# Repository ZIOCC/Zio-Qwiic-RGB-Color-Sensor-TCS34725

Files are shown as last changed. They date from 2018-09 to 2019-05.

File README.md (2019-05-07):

# Zio Qwiic RGB Color Sensor (TCS34725)

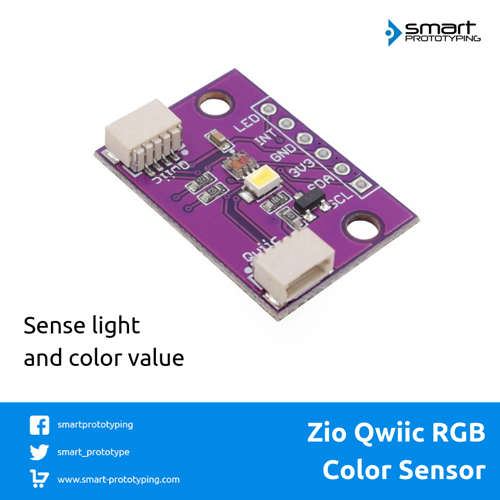
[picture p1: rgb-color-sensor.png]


> This product can be available for purchase [here](https://www.smart-prototyping.com/Zio-Qwiic-RGB-Color-Sensor-TCS34725).

#### Description

The Qwiic Color Sensor board features one of the best color sensor on the market to monitor a specific color value and light sensing.

The board features a TCS34725 with I2C interface and minimizes the IR and UV spectral to make the color measurements as accurate as possible. 
 
The high sensitivity, IR blocking filter and wide dynamic range (3.8M:1) with adjustable integration time and gain make the sensor a great solution for use under different light conditions and attenuating materials. 
 
Finally, we specified a nice neutral 4150°K temperature LED with a MOSFET driver onboard to illuminate what you're trying to sense. The LED can be easily turned on or off by any logic level output.
 
The Zio Qwiic RGB Color Sensor uses the Qwiic connector for deasy chain with any Qwiic compatible boards. Just in case you would like to use this board without the Qwiic connector, we have incorporated header pins. As well as if you’d like to access the LED and INT pins.

#### Specification

* Operation Voltage: 3.3V
* Interface: I2C (address 0x29)
* Dimensions:18.1x25.5mm
* Weight:1.2g

#### Links

* [PCB Source File and Schematic](https://github.com/ZIOCC/Zio-Qwiic-RGB-Color-Sensor-TCS34725)
* [TCS34725 Datasheet](https://ams.com/documents/20143/36005/TCS3472_DS000390_2-00.pdf/)
* [Adafruit TCS34725 master Library](https://github.com/adafruit/Adafruit_TCS34725)

> ###### About Zio
> Zio is a new line of open sourced, compact, and grid layout boards, fully integrated for Arduino and Qwiic ecosystem. Designed ideally for wearables, robotics, small-space limitations or other on the go projects. Check out other awesome Zio products [here](https://www.smart-prototyping.com/Zio).

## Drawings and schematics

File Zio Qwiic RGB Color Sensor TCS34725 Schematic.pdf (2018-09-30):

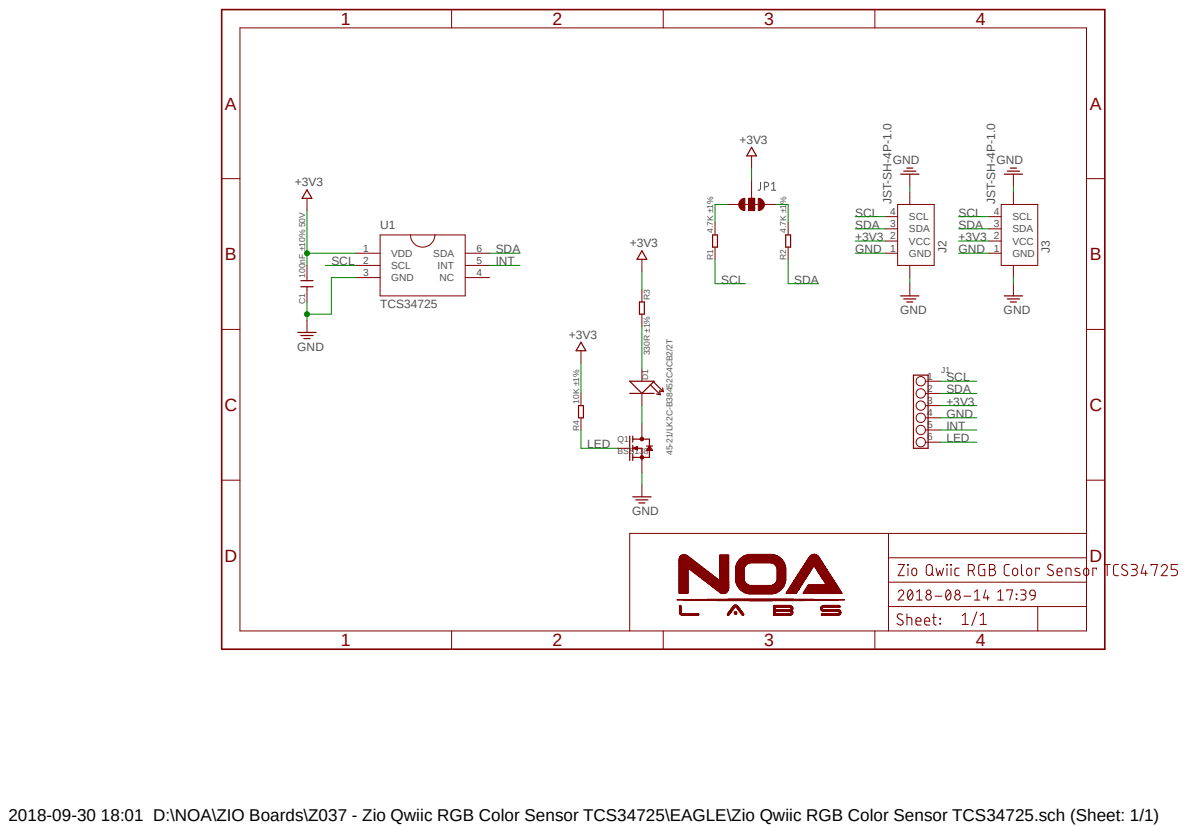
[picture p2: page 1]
GND; GND 4.7K ±1%; TCS34725; +3V3 100nF ±10% ⁵⁰V; 45⁻21/LK²C⁻B³⁸⁴⁵²C⁴CB²/2T 330R ±1%; BSS138 ¹⁰K ±1%; GND 1; VCC 2; SDA 3; SCL 4; J3 JST⁻SH⁻⁴P⁻¹.0; J2 JST⁻SH⁻⁴P⁻¹.0; VDD; SCL 2; GND 3; INT; SDA; 6 GND; SCL; INT LED LED

2018-09-30 18:01 D:\NOA\ZIO Boards\Z037 - Zio Qwiic RGB Color Sensor TCS34725\EAGLE\Zio Qwiic RGB Color Sensor TCS34725.sch (Sheet: 1/1)

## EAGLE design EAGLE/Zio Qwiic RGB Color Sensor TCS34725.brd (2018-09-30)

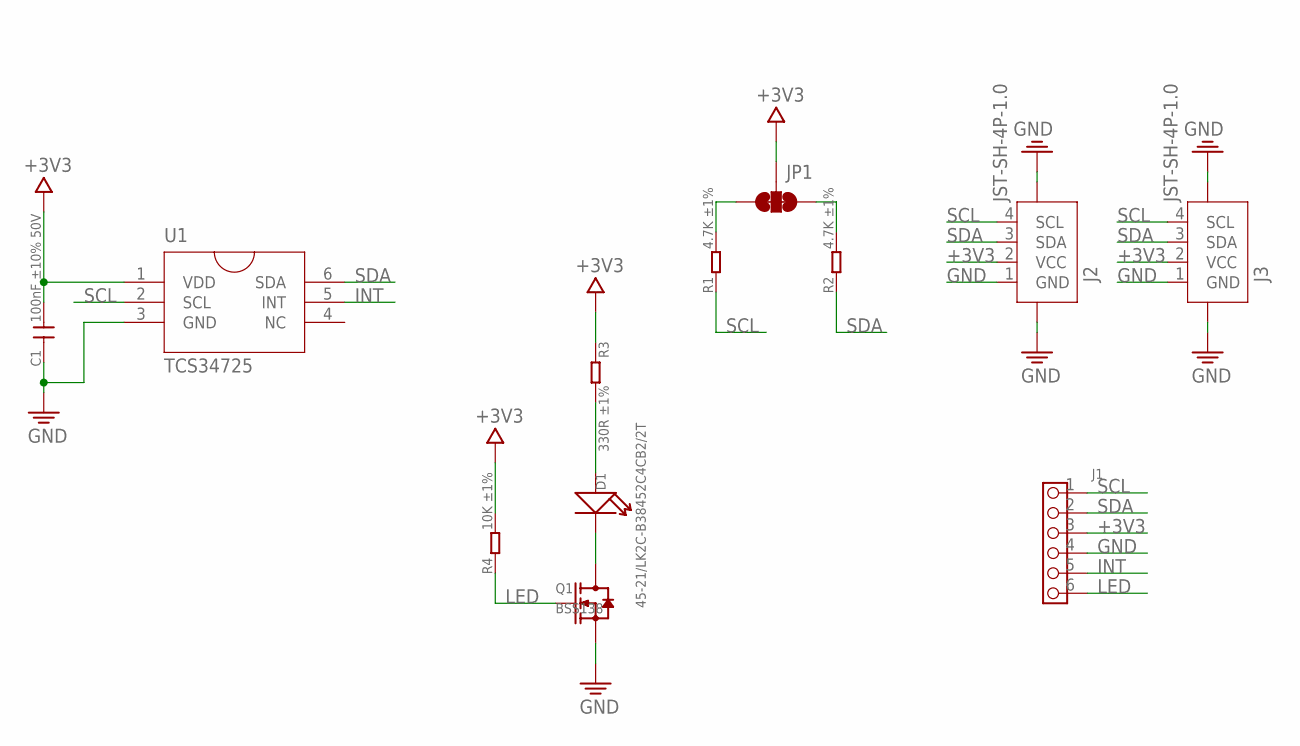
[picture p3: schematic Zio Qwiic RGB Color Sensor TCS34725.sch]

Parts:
C1: 100nF ±10% 50V; C0603
D1: 45-21/LK2C-B38452C4CB2/2T; EVERLIGHT_45-21
J1: HEADER-6P-60/35MIL; 6P-2.54-60/35MIL
J2, J3: JST-SH-4P-1.0; JST-SH-4P
JP1: SMT-JUMPER_3_2-NC_TRACE
Q1: BSS138; SOT23
R1, R2: 4.7K ±1%; R0603
R3: 330R ±1%; R0603
R4: 10K ±1%; R0603
U1: TCS34725; FN6_TCS3472

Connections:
+3V3: C1.2, J1.3, J2.2 (VCC), J3.2 (VCC), JP1.2, R3.1, R4.2, U1.1 (VDD)
GND: C1.1, J1.4, J2.1 (GND), J2.NC1 (5), J2.NC2 (6), J3.1 (GND), J3.NC1 (5), J3.NC2 (6), Q1.2 (S), U1.3 (GND)
INT: J1.5, U1.5 (INT)
LED: J1.6, Q1.1 (G), R4.1
unnamed: D1.A (+), R3.2
unnamed: D1.K (-), Q1.3 (D)
unnamed: JP1.3, R1.2
unnamed: JP1.1, R2.2
SCL: J1.1, J2.4 (SCL), J3.4 (SCL), R1.1, U1.2 (SCL)
SDA: J1.2, J2.3 (SDA), J3.3 (SDA), R2.1, U1.6 (SDA)

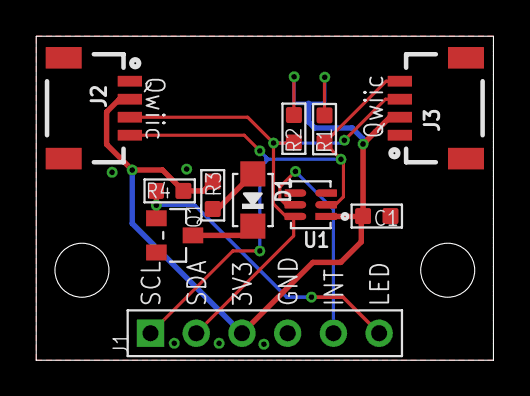
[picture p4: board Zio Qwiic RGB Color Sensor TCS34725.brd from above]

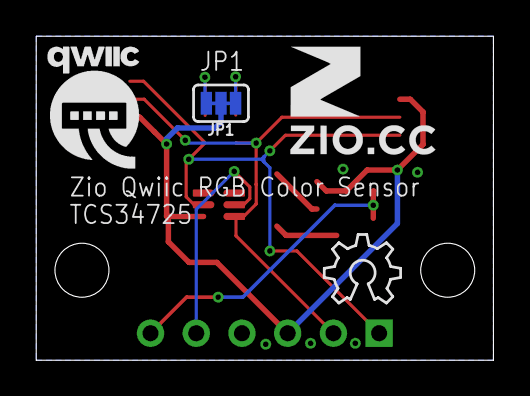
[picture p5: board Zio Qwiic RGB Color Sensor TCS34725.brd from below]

Board: 2 copper layers, 25.4 x 18.0 mm, 15 parts (4 on the bottom side), 10 nets.

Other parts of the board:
U$5: 6MM
U$6: OSHW_6X150_NOTEXT
U$7: QWIIC-LOGO-MEDIUM
